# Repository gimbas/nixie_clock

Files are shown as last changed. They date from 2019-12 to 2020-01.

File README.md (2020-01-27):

# Nixie Clock

yet another nixie tube clock, esp32 wifi enabled, temperature and humidity sensing, air quality sensing.

## Built With

* esp-idf
* eagle cad

## Authors

* **Rafael Silva** - *initial work* - [gimbas](https://github.com/gimbas)

See also the list of [contributors](https://github.com/gimbas/nixie_clock/graphs/contributors) who participated in this project.

## License

<br />This work is licensed under a <a rel="license" href="http://creativecommons.org/licenses/by-sa/4.0/">Creative Commons Attribution-ShareAlike 4.0 International License</a>.

## Acknowledgments

* HV power supply development and testing - [tonyp7](https://github.com/tonyp7/)

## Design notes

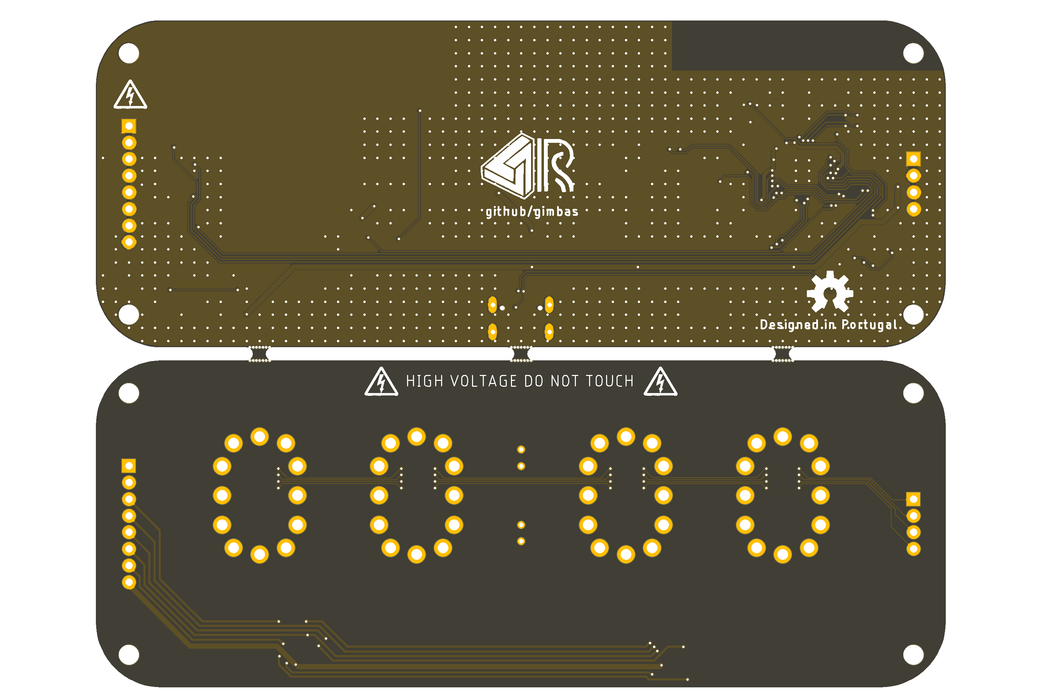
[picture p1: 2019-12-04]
pcb/nixie_clock_bot.png

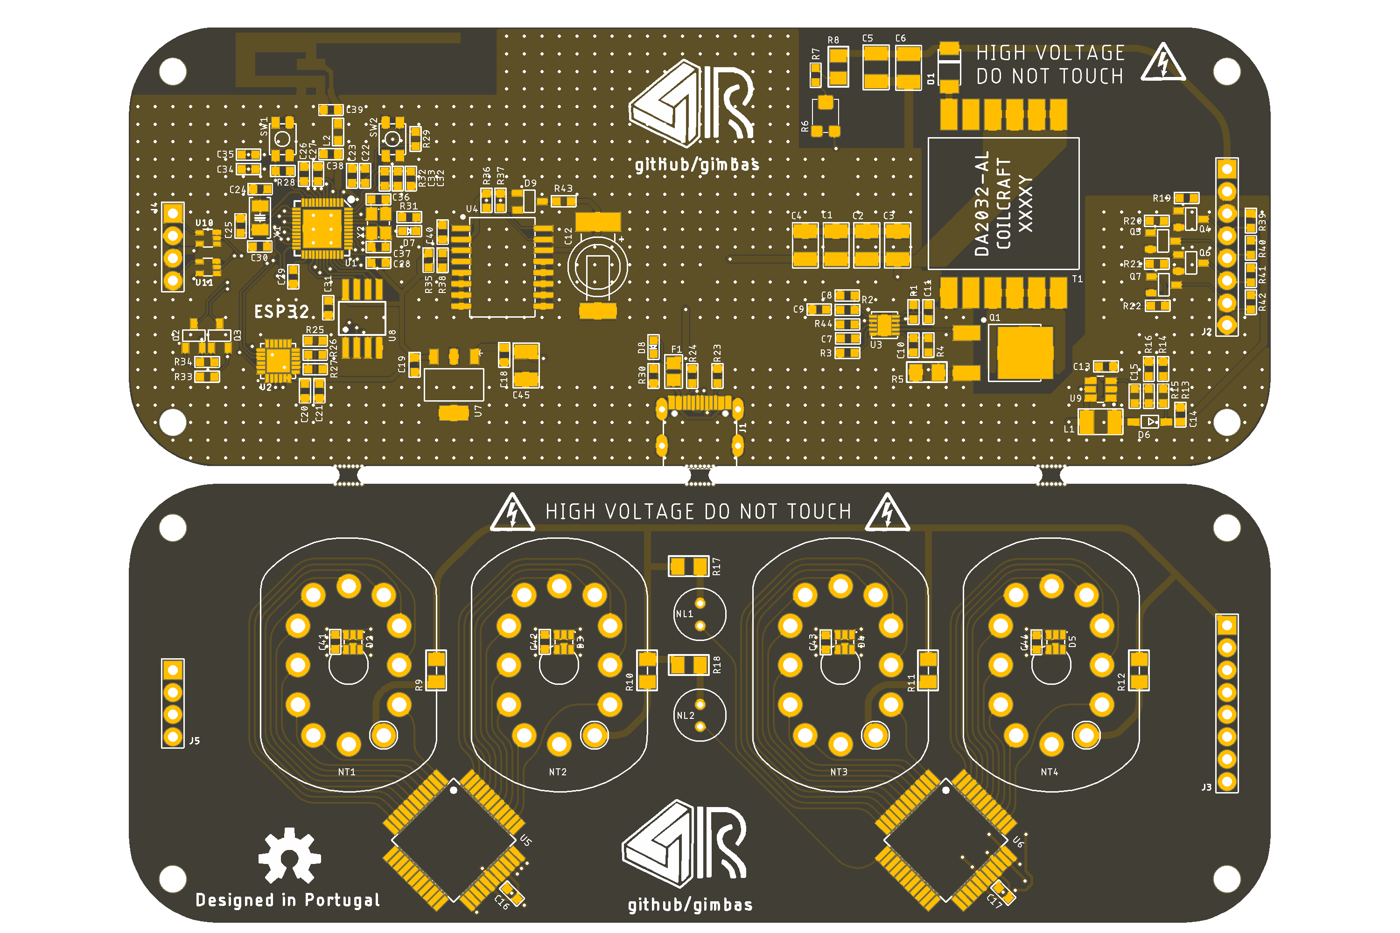
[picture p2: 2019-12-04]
pcb/nixie_clock_top.png

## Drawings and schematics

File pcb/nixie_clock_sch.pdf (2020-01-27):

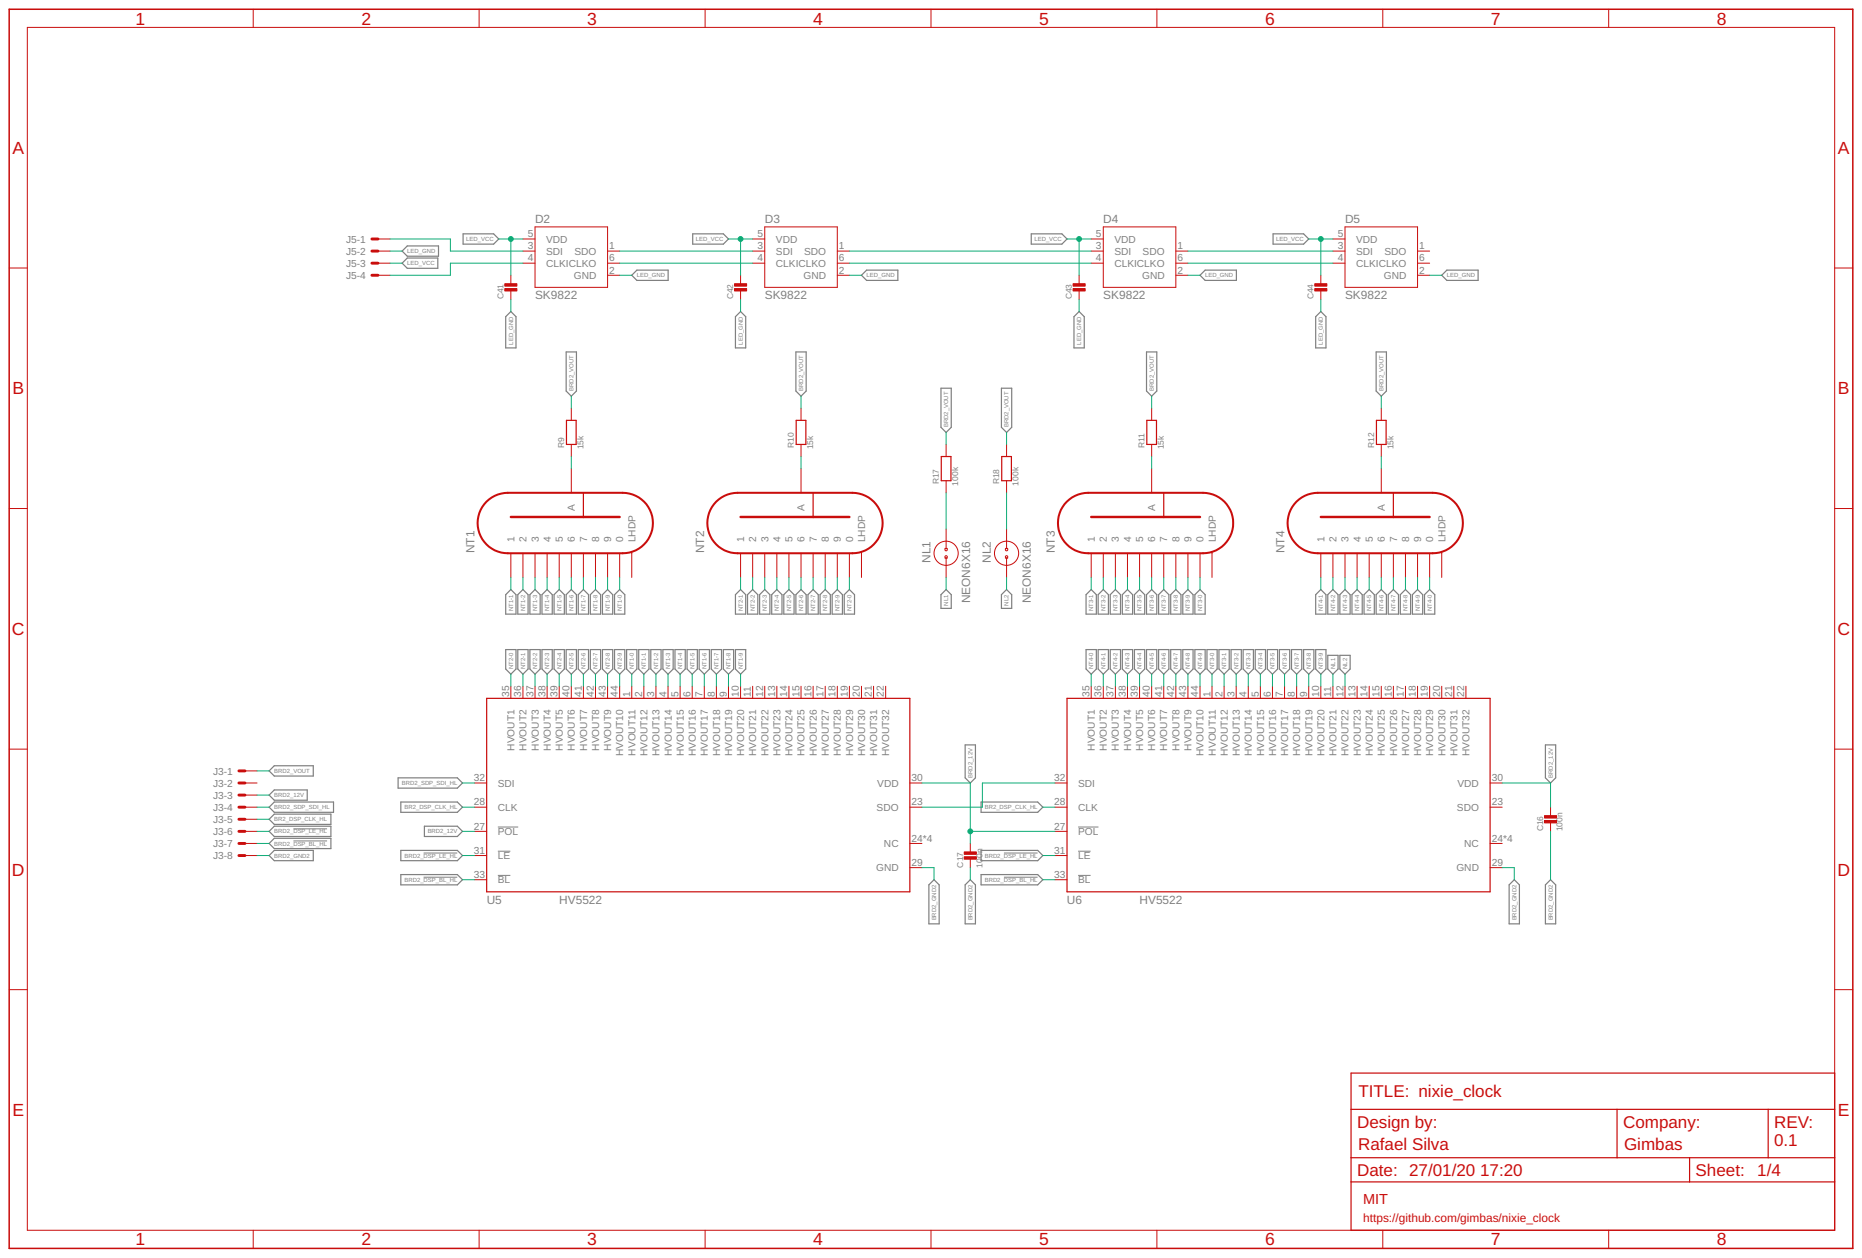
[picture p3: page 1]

Design by: Rafael Silva | Company: Gimbas | REV: 0.1

Date: 27/01/20 17:20 | Sheet: 1/4

MIT
https://github.com/gimbas/nixie_clock

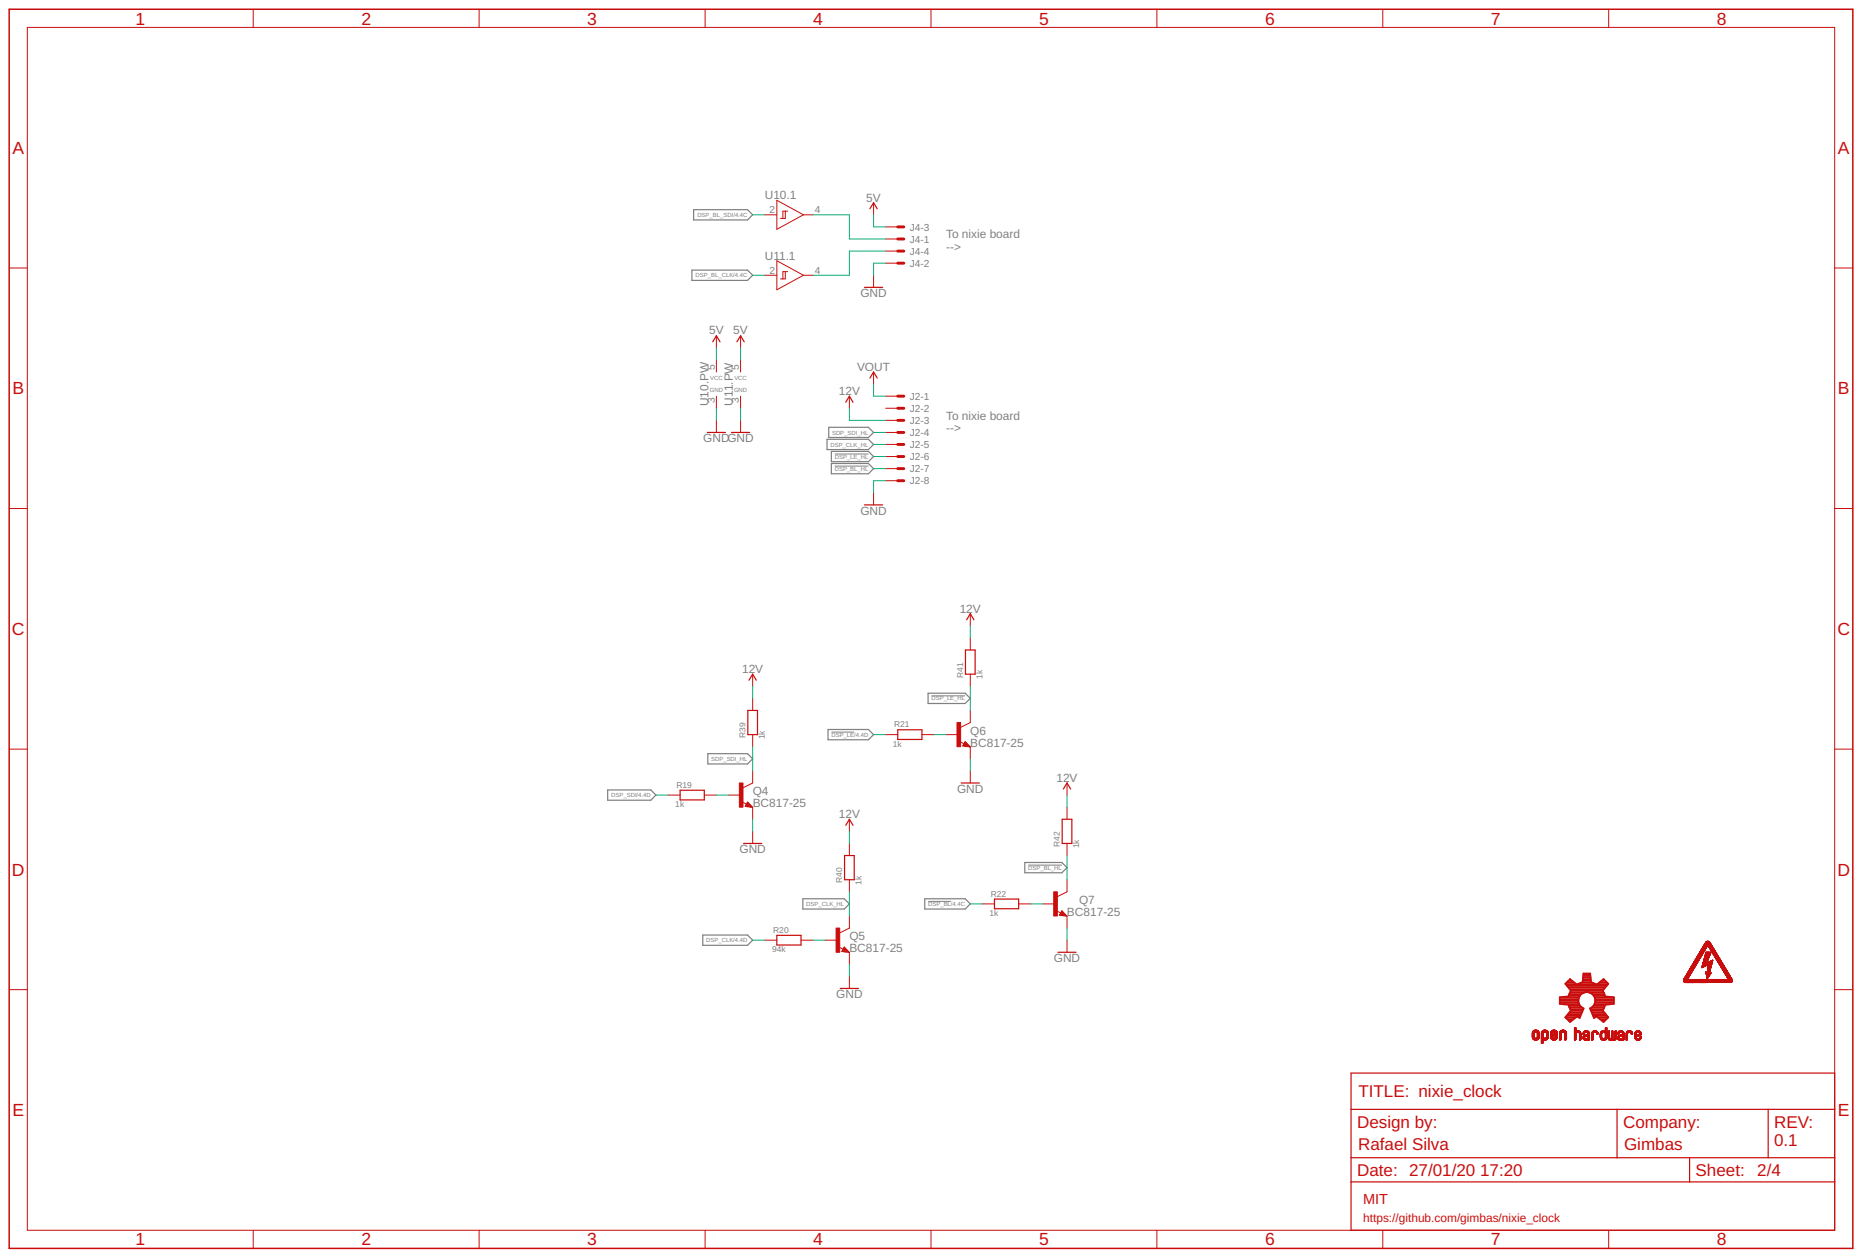
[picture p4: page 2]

Design by: Rafael Silva | Company: Gimbas | REV: 0.1

Date: 27/01/20 17:20 | Sheet: 2/4

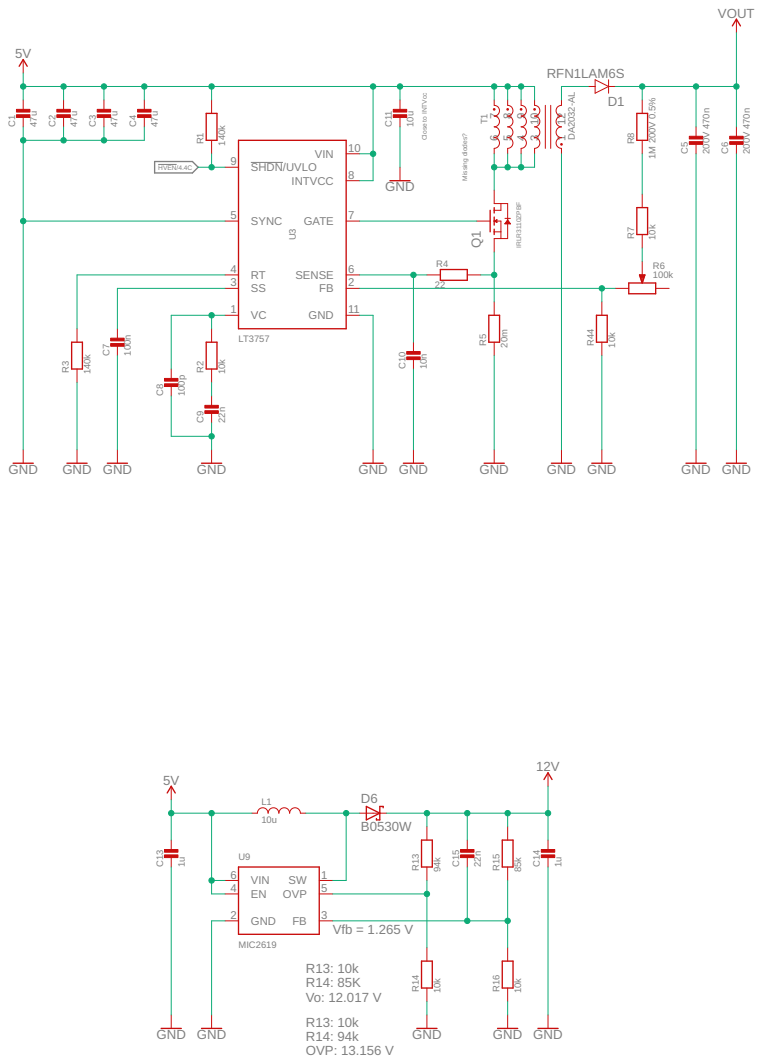
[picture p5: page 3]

Close to INTVcc Missing diodes?

Design by: Rafael Silva | Company: Gimbas | REV: 0.1

Date: 27/01/20 17:20 | Sheet: 3/4

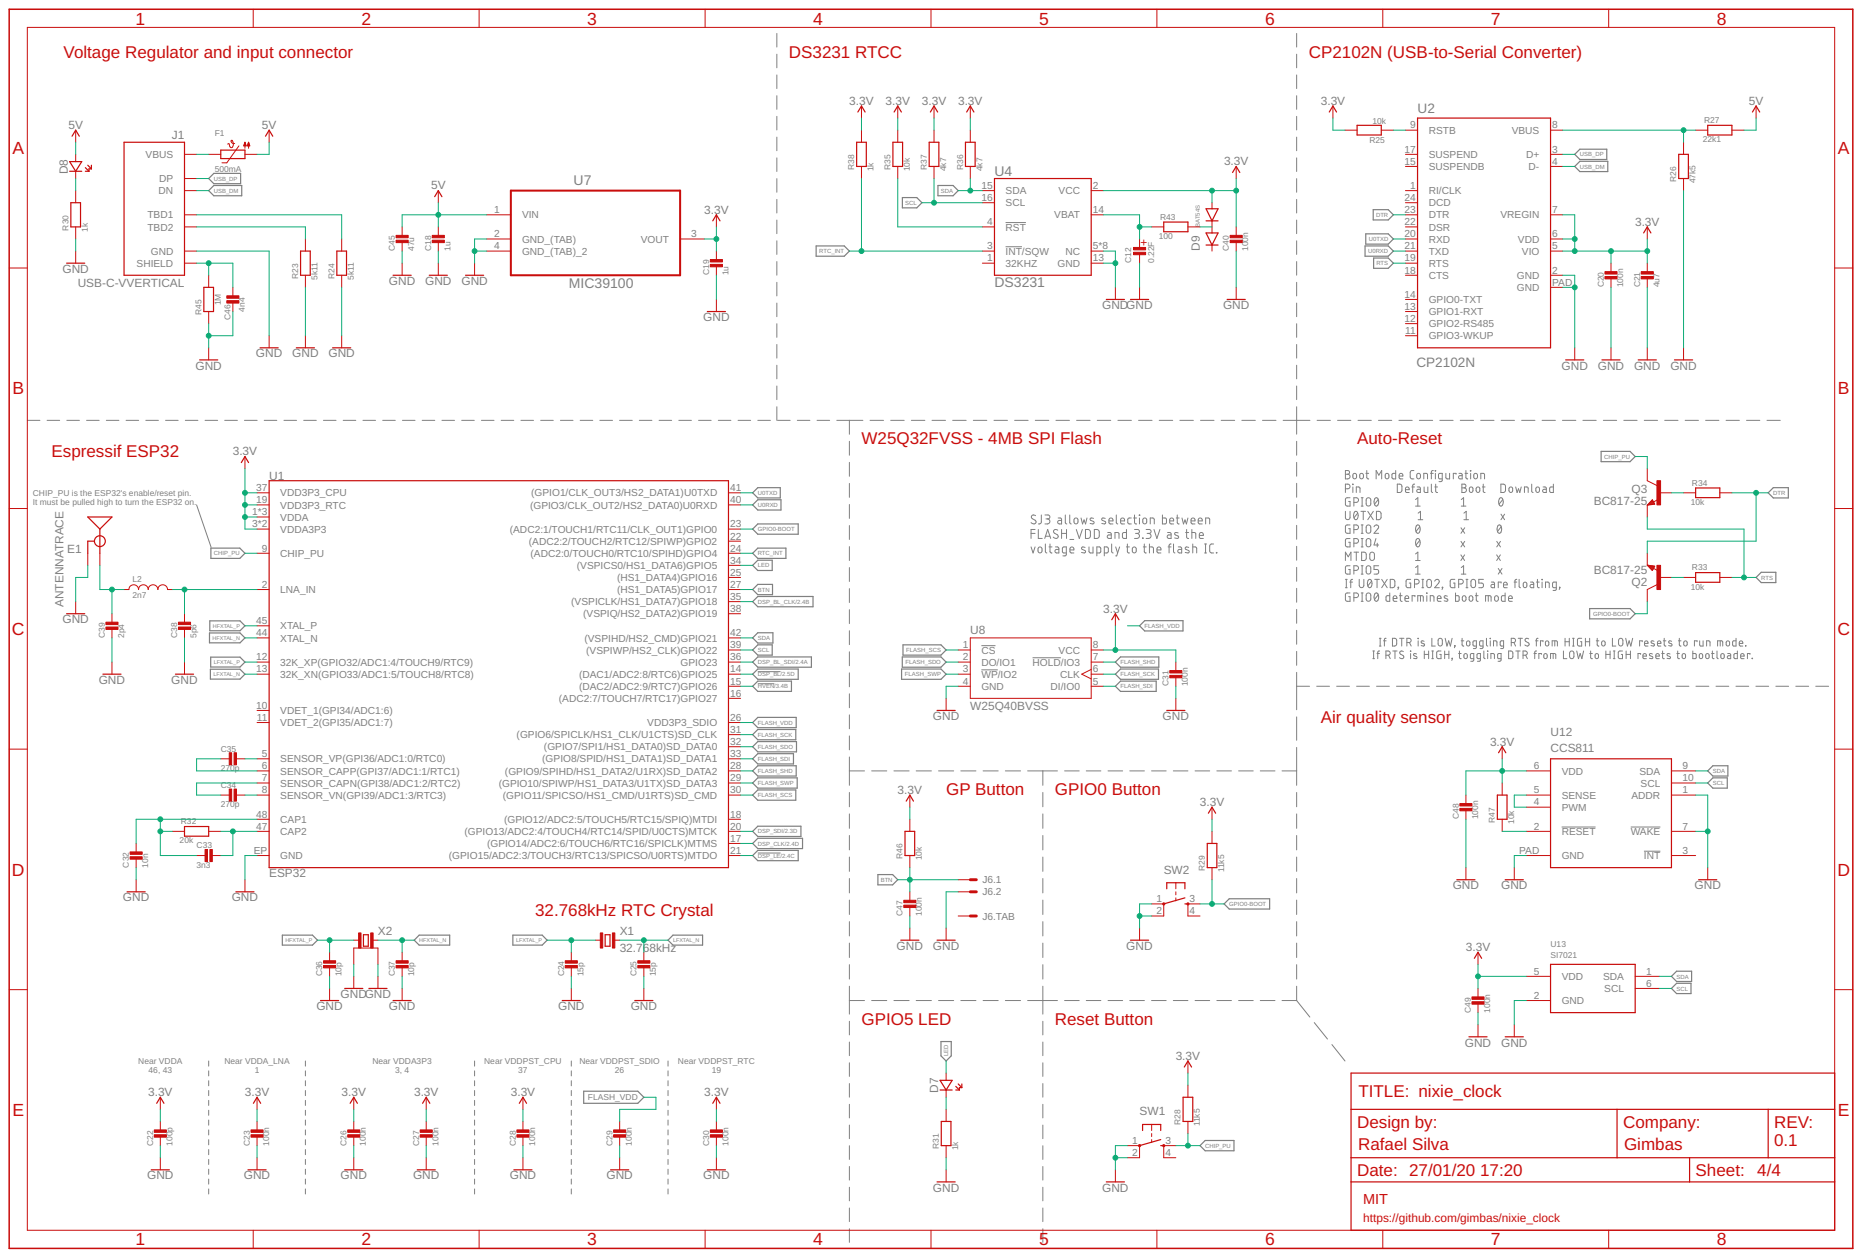
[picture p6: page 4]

CHIP_PU is the ESP32's enable/reset pin.
It must be pulled high to turn the ESP32 on.

Design by: Rafael Silva | Company: Gimbas | REV: 0.1

Date: 27/01/20 17:20 | Sheet: 4/4

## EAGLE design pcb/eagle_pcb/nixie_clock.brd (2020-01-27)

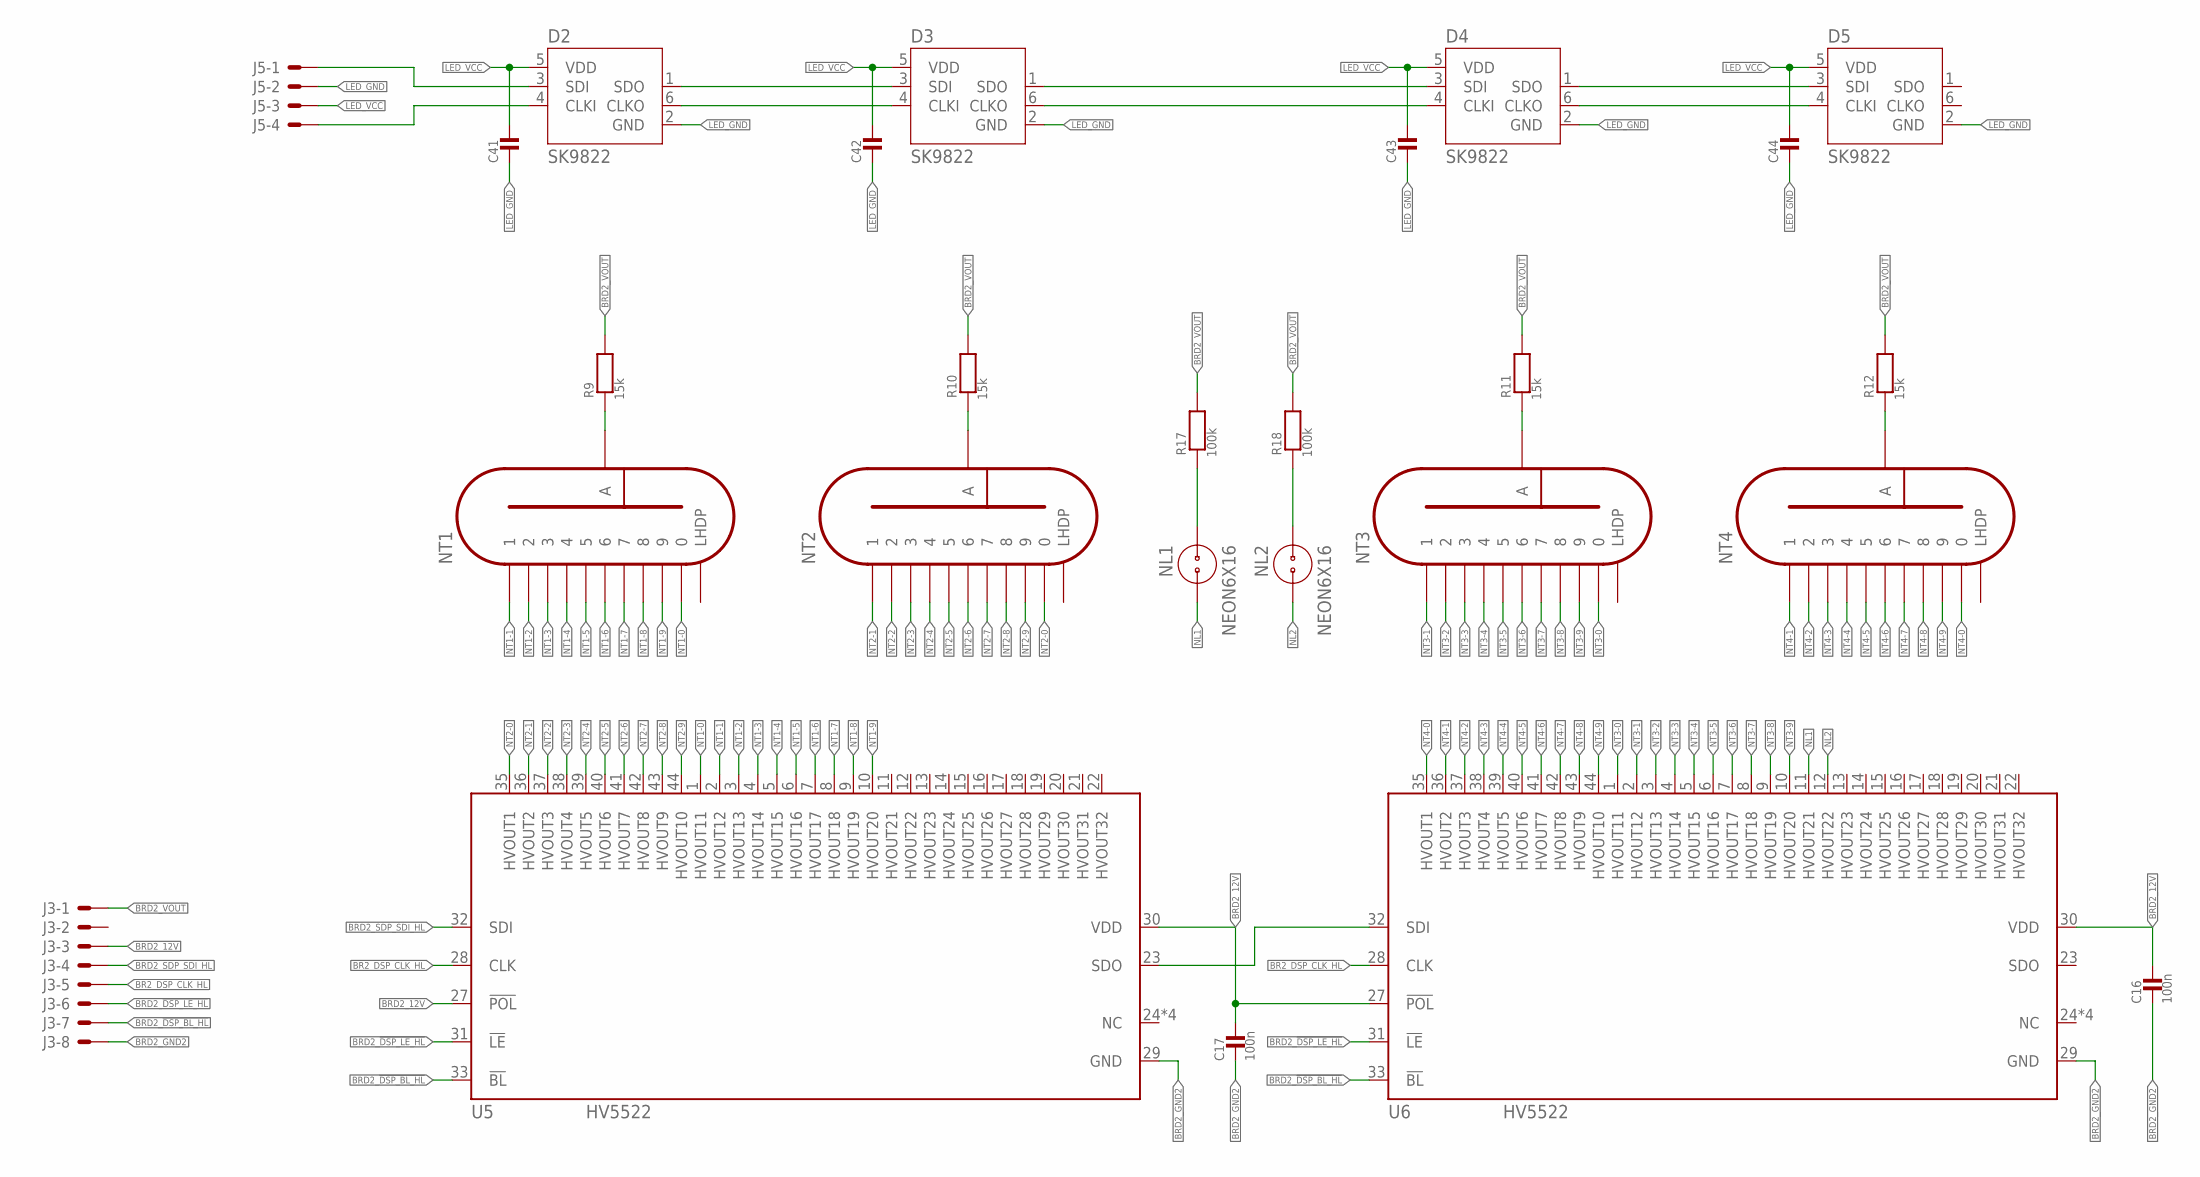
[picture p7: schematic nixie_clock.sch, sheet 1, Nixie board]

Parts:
C16, C17: 100n; 0603_WAVE
C41, C42, C43, C44: MLCC0603; 0603_WAVE
D2, D3, D4, D5: SK9822; 2020
J3: 8; 1X8_2.54
J5: 4; 1X4_2.54
NL1, NL2: NEON6X16; NL-6X16
NT1, NT2, NT3, NT4: IN-12B; IN-12
R9, R10, R11, R12: 15k; _1206
R17, R18: 100k; _1206
U5, U6: HV5522; QFP64

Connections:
BR2_DSP_CLK_HL: J3.5, U5.28 (CLK), U6.28 (CLK)
BRD2_12V: C16.P$1, C17.P$1, J3.3, U5.27 (!POL), U5.30 (VDD), U6.27 (!POL), U6.30 (VDD)
BRD2_!DSP_BL_HL: J3.7, U5.33 (!BL), U6.33 (!BL)
BRD2_!DSP_LE_HL: J3.6, U5.31 (!LE), U6.31 (!LE)
BRD2_GND2: C16.P$2, C17.P$2, J3.8, U5.29 (GND), U6.29 (GND)
BRD2_SDP_SDI_HL: J3.4, U5.32 (SDI)
BRD2_VOUT: J3.1, R9.2, R10.2, R11.2, R12.2, R17.2, R18.2
LED_GND: C41.P$2, C42.P$2, C43.P$2, C44.P$2, D2.2 (GND), D3.2 (GND), D4.2 (GND), D5.2 (GND), J5.2
LED_VCC: C41.P$1, C42.P$1, C43.P$1, C44.P$1, D2.5 (VDD), D3.5 (VDD), D4.5 (VDD), D5.5 (VDD), J5.3
unnamed: NT1.A, R9.1
unnamed: NT2.A, R10.1
unnamed: NT3.A, R11.1
unnamed: NT4.A, R12.1
unnamed: NL1.1, R17.1
unnamed: NL2.1, R18.1
unnamed: U5.23 (SDO), U6.32 (SDI)
unnamed: D2.3 (SDI), J5.1
unnamed: D2.4 (CLKI), J5.4
unnamed: D3.1 (SDO), D4.3 (SDI)
unnamed: D3.6 (CLKO), D4.4 (CLKI)
unnamed: D4.6 (CLKO), D5.4 (CLKI)
unnamed: D4.1 (SDO), D5.3 (SDI)
unnamed: D2.6 (CLKO), D3.4 (CLKI)
unnamed: D2.1 (SDO), D3.3 (SDI)
NL1: NL1.2, U6.11 (HVOUT21)
NL2: NL2.2, U6.12 (HVOUT22)
NT1-0: NT1.0, U5.1 (HVOUT11)
NT1-1: NT1.1, U5.2 (HVOUT12)
NT1-2: NT1.2, U5.3 (HVOUT13)
NT1-3: NT1.3, U5.4 (HVOUT14)
NT1-4: NT1.4, U5.5 (HVOUT15)
NT1-5: NT1.5, U5.6 (HVOUT16)
NT1-6: NT1.6, U5.7 (HVOUT17)
NT1-7: NT1.7, U5.8 (HVOUT18)
NT1-8: NT1.8, U5.9 (HVOUT19)
NT1-9: NT1.9, U5.10 (HVOUT20)
NT2-0: NT2.0, U5.35 (HVOUT1)
NT2-1: NT2.1, U5.36 (HVOUT2)
NT2-2: NT2.2, U5.37 (HVOUT3)
NT2-3: NT2.3, U5.38 (HVOUT4)
NT2-4: NT2.4, U5.39 (HVOUT5)
NT2-5: NT2.5, U5.40 (HVOUT6)
NT2-6: NT2.6, U5.41 (HVOUT7)
NT2-7: NT2.7, U5.42 (HVOUT8)
NT2-8: NT2.8, U5.43 (HVOUT9)
NT2-9: NT2.9, U5.44 (HVOUT10)
NT3-0: NT3.0, U6.1 (HVOUT11)
NT3-1: NT3.1, U6.2 (HVOUT12)
NT3-2: NT3.2, U6.3 (HVOUT13)
NT3-3: NT3.3, U6.4 (HVOUT14)
NT3-4: NT3.4, U6.5 (HVOUT15)
NT3-5: NT3.5, U6.6 (HVOUT16)
NT3-6: NT3.6, U6.7 (HVOUT17)
NT3-7: NT3.7, U6.8 (HVOUT18)
NT3-8: NT3.8, U6.9 (HVOUT19)
NT3-9: NT3.9, U6.10 (HVOUT20)
NT4-0: NT4.0, U6.35 (HVOUT1)
NT4-1: NT4.1, U6.36 (HVOUT2)
NT4-2: NT4.2, U6.37 (HVOUT3)
NT4-3: NT4.3, U6.38 (HVOUT4)
NT4-4: NT4.4, U6.39 (HVOUT5)
NT4-5: NT4.5, U6.40 (HVOUT6)
NT4-6: NT4.6, U6.41 (HVOUT7)
NT4-7: NT4.7, U6.42 (HVOUT8)
NT4-8: NT4.8, U6.43 (HVOUT9)
NT4-9: NT4.9, U6.44 (HVOUT10)

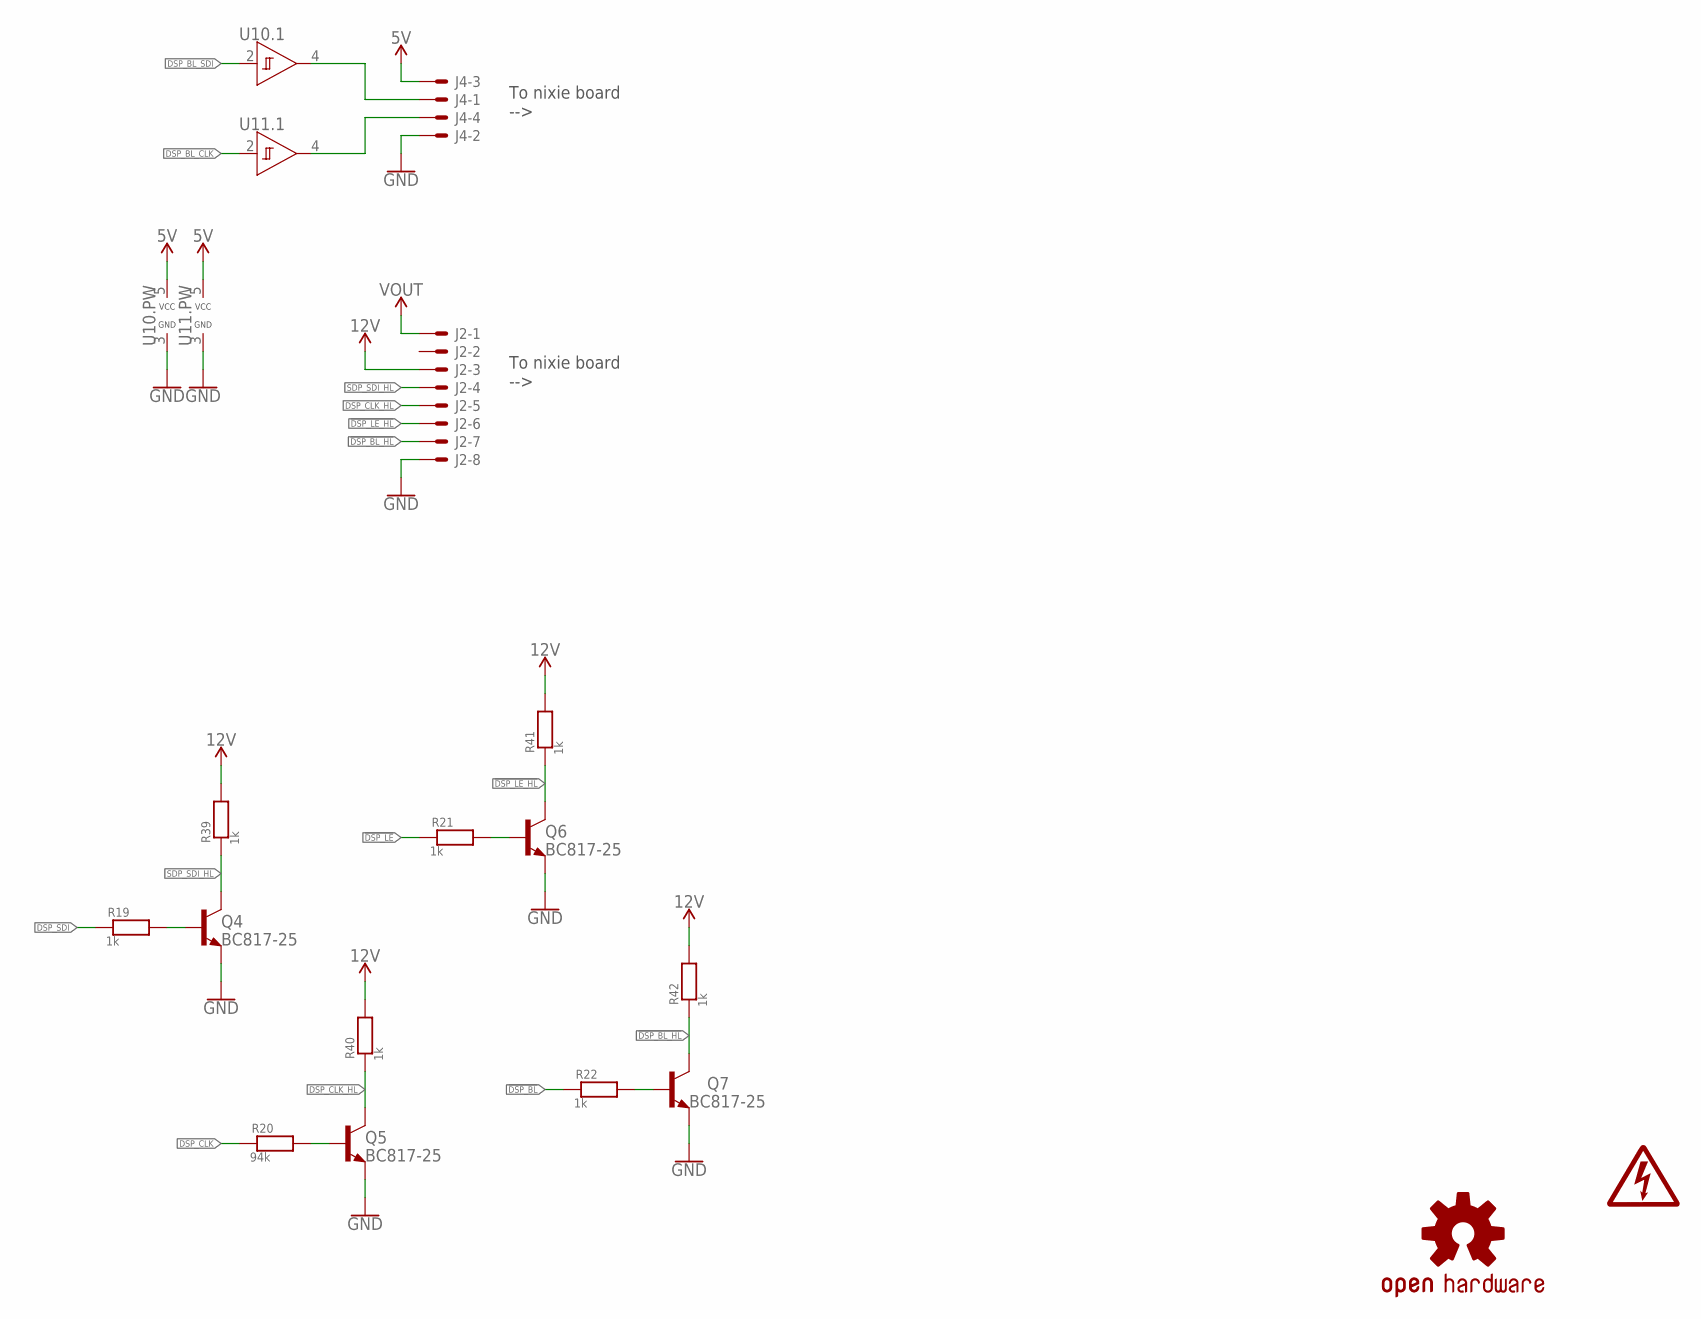
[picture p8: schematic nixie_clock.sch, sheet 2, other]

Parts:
J2: 8; 1X8_2.54
J4: 4; 1X4_2.54
LOGO3: OSHW-LOGOL; OSHW-LOGO-L
LOGO6: HV_WARNING
Q4, Q5, Q6, Q7: BC817-25; SOT-23-3
R19, R21, R22, R39, R40, R41, R42: 1k; 0603_WAVE
R20: 94k; 0603_WAVE
U10, U11: 74LVC1G17; SC70-5

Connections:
5V: J4.3, U10.5 (VCC), U11.5 (VCC); also elsewhere on the board
12V: J2.3, R39.P$2, R40.P$2, R41.P$2, R42.P$2; also elsewhere on the board
!DSP_BL: R22.P$1; also elsewhere on the board
!DSP_BL_HL: J2.7, Q7.P$3 (C03), R42.P$1
!DSP_LE: R21.P$1; also elsewhere on the board
!DSP_LE_HL: J2.6, Q6.P$3 (C03), R41.P$1
DSP_BL_CLK: U11.2 (A); also elsewhere on the board
DSP_BL_SDI: U10.2 (A); also elsewhere on the board
DSP_CLK: R20.P$1; also elsewhere on the board
DSP_CLK_HL: J2.5, Q5.P$3 (C03), R40.P$1
DSP_SDI: R19.P$1; also elsewhere on the board
GND: J2.8, J4.2, Q4.P$2 (EM2), Q5.P$2 (EM2), Q6.P$2 (EM2), Q7.P$2 (EM2), U10.3 (GND), U11.3 (GND); also elsewhere on the board
unnamed: Q4.P$1 (BA1), R19.P$2
unnamed: Q5.P$1 (BA1), R20.P$2
unnamed: Q7.P$1 (BA1), R22.P$2
unnamed: Q6.P$1 (BA1), R21.P$2
unnamed: J4.4, U11.4 (Y)
unnamed: J4.1, U10.4 (Y)
SDP_SDI_HL: J2.4, Q4.P$3 (C03), R39.P$1
VOUT: J2.1; also elsewhere on the board

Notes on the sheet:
To nixie board -->

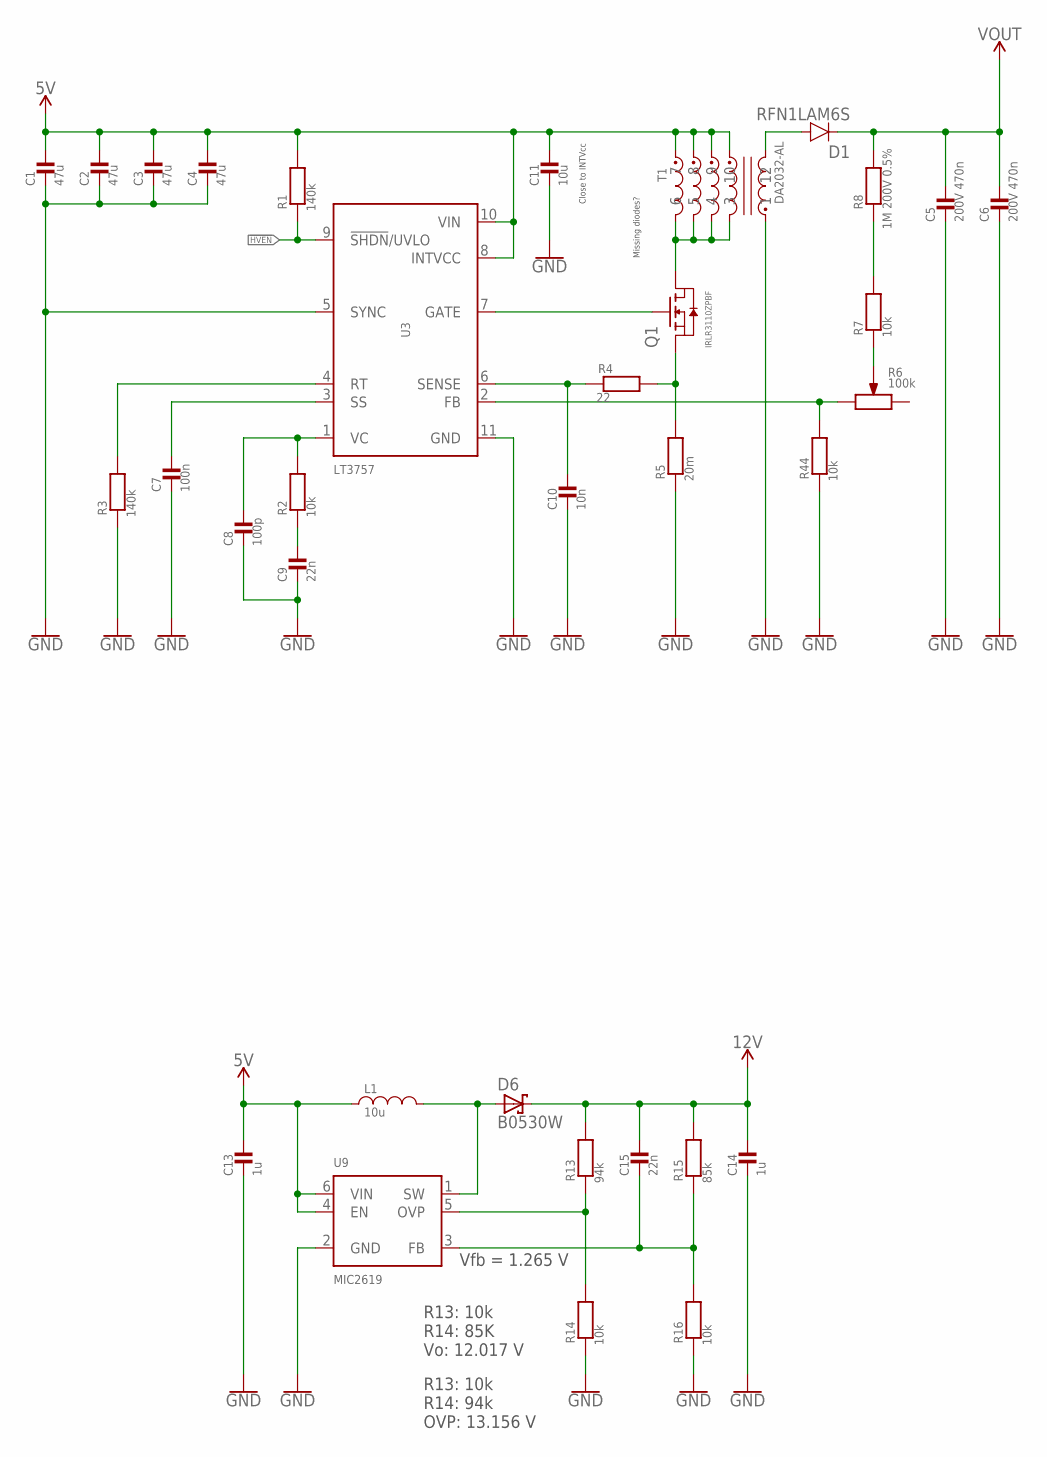
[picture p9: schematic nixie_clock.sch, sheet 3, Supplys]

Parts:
C1, C2, C3, C4: 47u; _1210
C5, C6: 200V 470n; _1210
C7: 100n; 0603_WAVE
C8: 100p; 0603_WAVE
C9, C15: 22n; 0603_WAVE
C10: 10n; 0603_WAVE
C11: 10u; 0603_WAVE
C13, C14: 1u; 0603_WAVE
D1: RFN1LAM6S; SOD-128
D6: B0530W; SOD-123
L1: 10u; _1210
Q1: IRLR3110ZPBF; D-PAK
R1, R3: 140k; 0603_WAVE
R2, R7, R14, R16, R44: 10k; 0603_WAVE
R4: 22; 0603_WAVE
R5: 20m; _1206
R6: 100k; TC33X
R8: 1M 200V 0.5%; _1206
R13: 94k; 0603_WAVE
R15: 85k; 0603_WAVE
T1: DA2032-AL
U3: LT3757; DFN10-2
U9: MIC2619; SOT-23-6N

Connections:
5V: C1.1, C2.1, C3.1, C4.1, C11.P$1, C13.P$1, L1.1, R1.P$2, T1.7, T1.8, T1.9, T1.10, U3.8 (INTVCC), U3.10 (VIN), U9.4 (EN), U9.6 (VIN); also elsewhere on the board
12V: C14.P$1, C15.P$1, D6.C, R13.P$2, R15.P$2; also elsewhere on the board
!HVEN: R1.P$1, U3.9 (!SHDN!/UVLO); also elsewhere on the board
GND: C1.2, C2.2, C3.2, C4.2, C5.2, C6.2, C7.P$2, C8.P$2, C9.P$2, C10.P$2, C11.P$2, C13.P$2, C14.P$2, R3.P$1, R5.1, R14.P$1, R16.P$1, R44.P$1, T1.1, U3.5 (SYNC), U3.11 (GND), U9.2 (GND); also elsewhere on the board
unnamed: D1.AN, T1.12
unnamed: C10.P$1, R4.P$1, U3.6 (SENSE)
unnamed: Q1.L (G1), U3.7 (GATE)
unnamed: Q1.P (D1), T1.3, T1.4, T1.5, T1.6
unnamed: Q1.R (S1), R4.P$2, R5.2
unnamed: R6.2, R7.P$1
unnamed: R7.P$2, R8.1
unnamed: C8.P$1, R2.P$2, U3.1 (VC)
unnamed: C9.P$1, R2.P$1
unnamed: C7.P$1, U3.3 (SS)
unnamed: R3.P$2, U3.4 (RT)
unnamed: D6.A, L1.2, U9.1 (SW)
unnamed: R13.P$1, R14.P$2, U9.5 (OVP)
unnamed: C15.P$2, R15.P$1, R16.P$2, U9.3 (FB)
unnamed: R6.3, R44.P$2, U3.2 (FB)
VOUT: C5.1, C6.1, D1.CAT, R8.2; also elsewhere on the board

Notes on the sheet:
Close to INTVcc
Missing diodes?
Vfb = 1.265 V
R13: 10k R14: 85K Vo: 12.017 V
R13: 10k R14: 94k OVP: 13.156 V

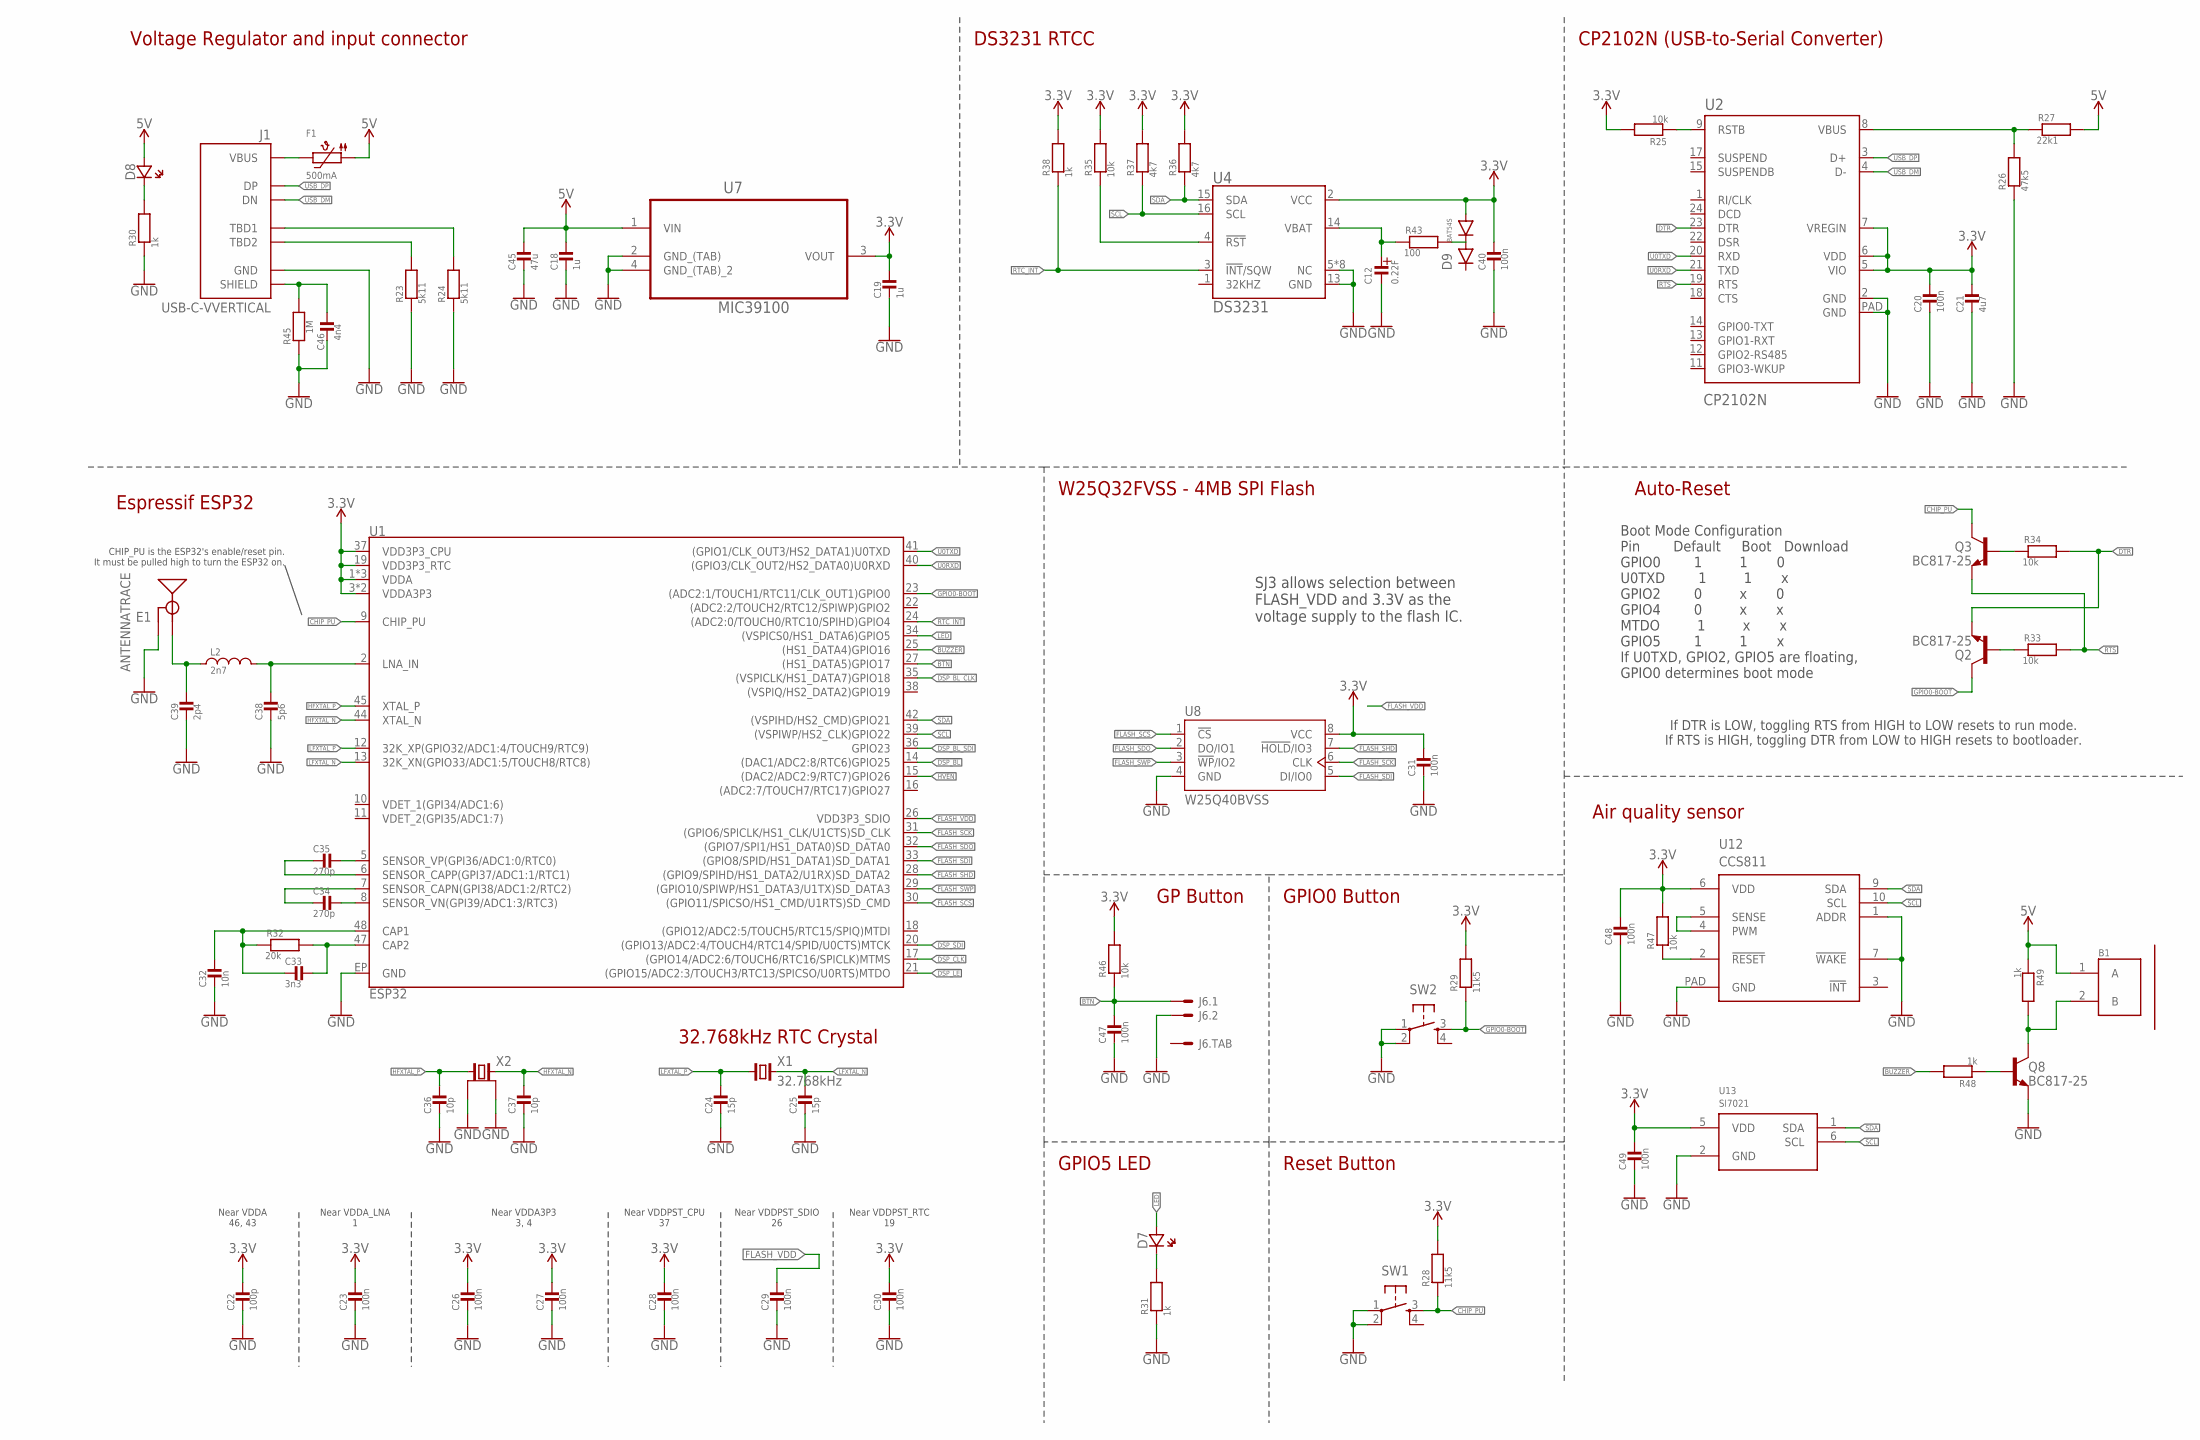
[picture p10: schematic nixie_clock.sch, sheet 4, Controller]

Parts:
B1: PKLCS1212E2400-R1; BUZZ_PIEZO_SMD
C12: 0.22F; DSK-614/621
C18, C19: 1u; 0603_WAVE
C20, C23, C26, C27, C28, C29, C30, C31, C40, C47, C48, C49: 100n; 0603_WAVE
C21: 4u7; 0603_WAVE
C22: 100p; 0603_WAVE
C24, C25: 15p; 0603_WAVE
C32: 10n; 0603_WAVE
C33: 3n3; 0603_WAVE
C34, C35: 270p; 0603_WAVE
C36, C37: 10p; 0603_WAVE
C38: 5p6; 0603_WAVE
C39: 2p4; 0603_WAVE
C45: 47u; _1210
C46: 4n4; 0603_WAVE
D7, D8: LED0603; CHIPLED_0603
D9: BAT54S; SOT-23-3
E1: ANTENNATRACE; TRACE_ANTENNA_2.4GHZ_25.7MM
F1: 500mA; 0805
J1: USB-C-VVERTICAL; USB-C-V
J6: PH-2; JST_PH_SMD_2
L2: 2n7; _0603
Q2, Q3, Q8: BC817-25; SOT-23-3
R23, R24: 5k11; 0603_WAVE
R25, R33, R34, R35, R46, R47: 10k; 0603_WAVE
R26: 47k5; 0603_WAVE
R27: 22k1; 0603_WAVE
R28, R29: 11k5; 0603_WAVE
R30, R31, R38, R48, R49: 1k; 0603_WAVE
R32: 20k; 0603_WAVE
R36, R37: 4k7; 0603_WAVE
R43: 100; 0603_WAVE
R45: 1M; 0603_WAVE
SW1, SW2: PUSH_BUTTON3X4X2; 3X4X2
U1: ESP32; QFN48-0.4MM
U2: CP2102N; QFN24
U4: DS3231; SOIC-16
U7: MIC39100; SOT230P700X180-4N
U8: W25Q40BVSS; SO08-SS
U12: CCS811; LGA10
U13: SI7021; DFN6
X1: 32.768kHz; 2-SMD-3215
X2: 26MHz; 4-SMD-3225

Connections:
3.3V: C19.P$1, C20.P$1, C21.P$1, C22.P$1, C23.P$1, C26.P$1, C27.P$1, C28.P$1, C30.P$1, C31.P$1, C40.P$1, C48.P$1, C49.P$1, D9.P$1 (1), R25.P$2, R28.P$2, R29.P$2, R35.P$2, R36.P$2, R37.P$2, R38.P$2, R46.P$2, R47.P$2, U1.1 (VDDA), U1.3 (VDDA3P3), U1.4 (VDDA3P3), U1.19 (VDD3P3_RTC), U1.37 (VDD3P3_CPU), U1.43 (VDDA), U1.46 (VDDA), U2.5 (VIO), U2.6 (VDD), U2.7 (VREGIN), U4.2 (VCC), U7.3 (VOUT), U8.8 (VCC), U12.6 (VDD), U13.5 (VDD)
5V: B1.1 (A), C18.P$1, C45.1, D8.A (AN), F1.1, R27.P$2, R49.P$1, U7.1 (VIN); also elsewhere on the board
!DSP_BL: U1.14 ((DAC1/ADC2:8/RTC6)GPIO25); also elsewhere on the board
!DSP_LE: U1.21 ((GPIO15/ADC2:3/TOUCH3/RTC13/SPICSO/U0RT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); also elsewhere on the board
!HVEN: U1.15 ((DAC2/ADC2:9/RTC7)GPIO26); also elsewhere on the board
BTN: C47.P$1, J6.1, R46.P$1, U1.27 ((HS1_DATA5)GPIO17)
BUZZER: R48.P$2, U1.25 ((HS1_DATA4)GPIO16)
CHIP_PU: Q3.P$3 (C03), R28.P$1, SW1.3 (4), U1.9 (CHIP_PU)
DSP_BL_CLK: U1.35 ((VSPICLK/HS1_DATA7)GPIO18); also elsewhere on the board
DSP_BL_SDI: U1.36 (GPIO23); also elsewhere on the board
DSP_CLK: U1.17 ((GPIO14/ADC2:6/TOUCH6/RTC16/SPICLK)MTMS); also elsewhere on the board
DSP_SDI: U1.20 ((GPIO13/ADC2:4/TOUCH4/RTC14/SPID/U0CTS)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); also elsewhere on the board
DTR: Q2.P$2 (EM2), R34.P$2, U2.23 (DTR)
FLASH_SCK: U1.31 ((GPIO6/SPICLK/HS1_CLK/U1CTS)SD_CLK), U8.6 (CLK)
FLASH_SCS: U1.30 ((GPIO11/SPICSO/HS1_CMD/U1RTS)SD_CMD), U8.1 (!CS!)
FLASH_SDI: U1.33 ((GPIO8/SPID/HS1_DATA1)SD_DATA1), U8.5 (DI/IO0)
FLASH_SDO: U1.32 ((GPIO7/SPI1/HS1_DATA0)SD_DATA0), U8.2 (DO/IO1)
FLASH_SHD: U1.28 ((GPIO9/SPIHD/HS1_DATA2/U1RX)SD_DATA2), U8.7 (!HOLD!/IO3)
FLASH_SWP: U1.29 ((GPIO10/SPIWP/HS1_DATA3/U1TX)SD_DATA3), U8.3 (!WP!/IO2)
FLASH_VDD: C29.P$1, U1.26 (VDD3P3_SDIO)
GND: C12.2 (CA), C18.P$2, C19.P$2, C20.P$2, C21.P$2, C22.P$2, C23.P$2, C24.P$2, C25.P$2, C26.P$2, C27.P$2, C28.P$2, C29.P$2, C30.P$2, C31.P$2, C32.P$2, C36.P$2, C37.P$2, C38.P$2, C39.P$2, C40.P$2, C45.2, C46.P$2, C47.P$2, C48.P$2, C49.P$2, E1.GND, E1.GND2 (GND), J1.1 (GND), J1.2 (GND), J1.15 (GND), J1.16 (GND), J6.2, Q8.P$2 (EM2), R23.P$1, R24.P$1, R26.P$1, R30.P$1, R31.P$1, R45.P$1, SW1.1, SW1.2, SW2.1, SW2.2, U1.EP (GND), U2.2 (GND), U2.PAD (GND), U4.5 (NC), U4.6 (NC), U4.7 (NC), U4.8 (NC), U4.9 (NC), U4.10 (NC), U4.11 (NC), U4.12 (NC), U4.13 (GND), U7.2 (GND_(TAB)), U7.4 (GND_(TAB)_2), U8.4 (GND), U12.1 (ADDR), U12.7 (!WAKE), U12.PAD (GND), U13.2 (GND), X2.1 (GND), X2.3 (GND); also elsewhere on the board
GPIO0-BOOT: Q2.P$3 (C03), R29.P$1, SW2.3 (4), U1.23 ((ADC2:1/TOUCH1/RTC11/CLK_OUT1)GPIO0)
HFXTAL_N: C37.P$1, U1.44 (XTAL_N), X2.4 (2)
HFXTAL_P: C36.P$1, U1.45 (XTAL_P), X2.2 (1)
LED: D7.A (AN), U1.34 ((VSPICS0/HS1_DATA6)GPIO5)
LFXTAL_N: C25.P$1, U1.13 (32K_XN(GPIO33/ADC1:5/TOUCH8/RTC8)), X1.2
LFXTAL_P: C24.P$1, U1.12 (32K_XP(GPIO32/ADC1:4/TOUCH9/RTC9)), X1.1
unnamed: C39.P$1, E1.ANT (SIGNAL), L2.1
unnamed: D9.P$3 (3), R43.P$2
unnamed: C46.P$1, J1.S1 (SHIELD), J1.S2 (SHIELD), J1.S3 (SHIELD), J1.S4 (SHIELD), R45.P$2
unnamed: R47.P$1, U12.2 (!RESET)
unnamed: U12.4 (PWM), U12.5 (SENSE)
unnamed: B1.2 (B), Q8.P$3 (C03), R49.P$2
unnamed: Q8.P$1 (BA1), R48.P$1
unnamed: F1.2, J1.3 (VBUS), J1.4 (VBUS), J1.13 (VBUS), J1.14 (VBUS)
unnamed: J1.6 (TBD2), R23.P$2
unnamed: J1.11 (TBD1), R24.P$2
unnamed: R25.P$1, U2.9 (RSTB)
unnamed: D8.C (CA), R30.P$2
unnamed: R26.P$2, R27.P$1, U2.8 (VBUS)
unnamed: D7.C (CA), R31.P$2
unnamed: C33.P$1, R32.P$2, U1.47 (CAP2)
unnamed: C34.P$1, U1.8 (SENSOR_VN(GPI39/ADC1:3/RTC3))
unnamed: C32.P$1, C33.P$2, R32.P$1, U1.48 (CAP1)
unnamed: C35.P$1, U1.5 (SENSOR_VP(GPI36/ADC1:0/RTC0))
unnamed: C34.P$2, U1.7 (SENSOR_CAPN(GPI38/ADC1:2/RTC2))
unnamed: C35.P$2, U1.6 (SENSOR_CAPP(GPI37/ADC1:1/RTC1))
unnamed: C38.P$1, L2.2, U1.2 (LNA_IN)
unnamed: Q2.P$1 (BA1), R33.P$1
unnamed: Q3.P$1 (BA1), R34.P$1
unnamed: C12.1 (AN), R43.P$1, U4.14 (VBAT)
unnamed: R35.P$1, U4.4 (!RST)
RTC_INT: R38.P$1, U1.24 ((ADC2:0/TOUCH0/RTC10/SPIHD)GPIO4), U4.3 (!INT!/SQW)
RTS: Q3.P$2 (EM2), R33.P$2, U2.19 (RTS)
SCL: R37.P$1, U1.39 ((VSPIWP/HS2_CLK)GPIO22), U4.16 (SCL), U12.10 (SCL), U13.6 (SCL)
SDA: R36.P$1, U1.42 ((VSPIHD/HS2_CMD)GPIO21), U4.15 (SDA), U12.9 (SDA), U13.1 (SDA)
U0RXD: U1.40 ((GPIO3/CLK_OUT2/HS2_DATA0)U0RXD), U2.21 (TXD)
U0TXD: U1.41 ((GPIO1/CLK_OUT3/HS2_DATA1)U0TXD), U2.20 (RXD)
USB_DM: J1.7 (DN), J1.10 (DN), U2.4 (D-)
USB_DP: J1.8 (DP), J1.9 (DP), U2.3 (D+)

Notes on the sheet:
Near VDDA 46, 43
Near VDDA_LNA 1
Near VDDA3P3 3, 4
Near VDDPST_CPU 37
Near VDDPST_SDIO 26
Near VDDPST_RTC 19
Boot Mode Configuration Pin Default Boot Download GPIO0 1 1 0 U0TXD 1 1 x GPIO2 0 x 0 GPIO4 0 x x MTDO 1 x x GPIO5 1 1 x If U0TXD, GPIO2, GPIO5 are floating, GPIO0 determines boot mode
CP2102N (USB-to-Serial Converter)
Voltage Regulator and input connector
Auto-Reset
Espressif ESP32
W25Q32FVSS - 4MB SPI Flash
32.768kHz RTC Crystal
GPIO0 Button
Reset Button
GPIO5 LED
SJ3 allows selection between FLASH_VDD and 3.3V as the voltage supply to the flash IC.
If DTR is LOW, toggling RTS from HIGH to LOW resets to run mode. If RTS is HIGH, toggling DTR from LOW to HIGH resets to bootloader.
CHIP_PU is the ESP32's enable/reset pin. It must be pulled high to turn the ESP32 on.
DS3231 RTCC
GP Button
Air quality sensor

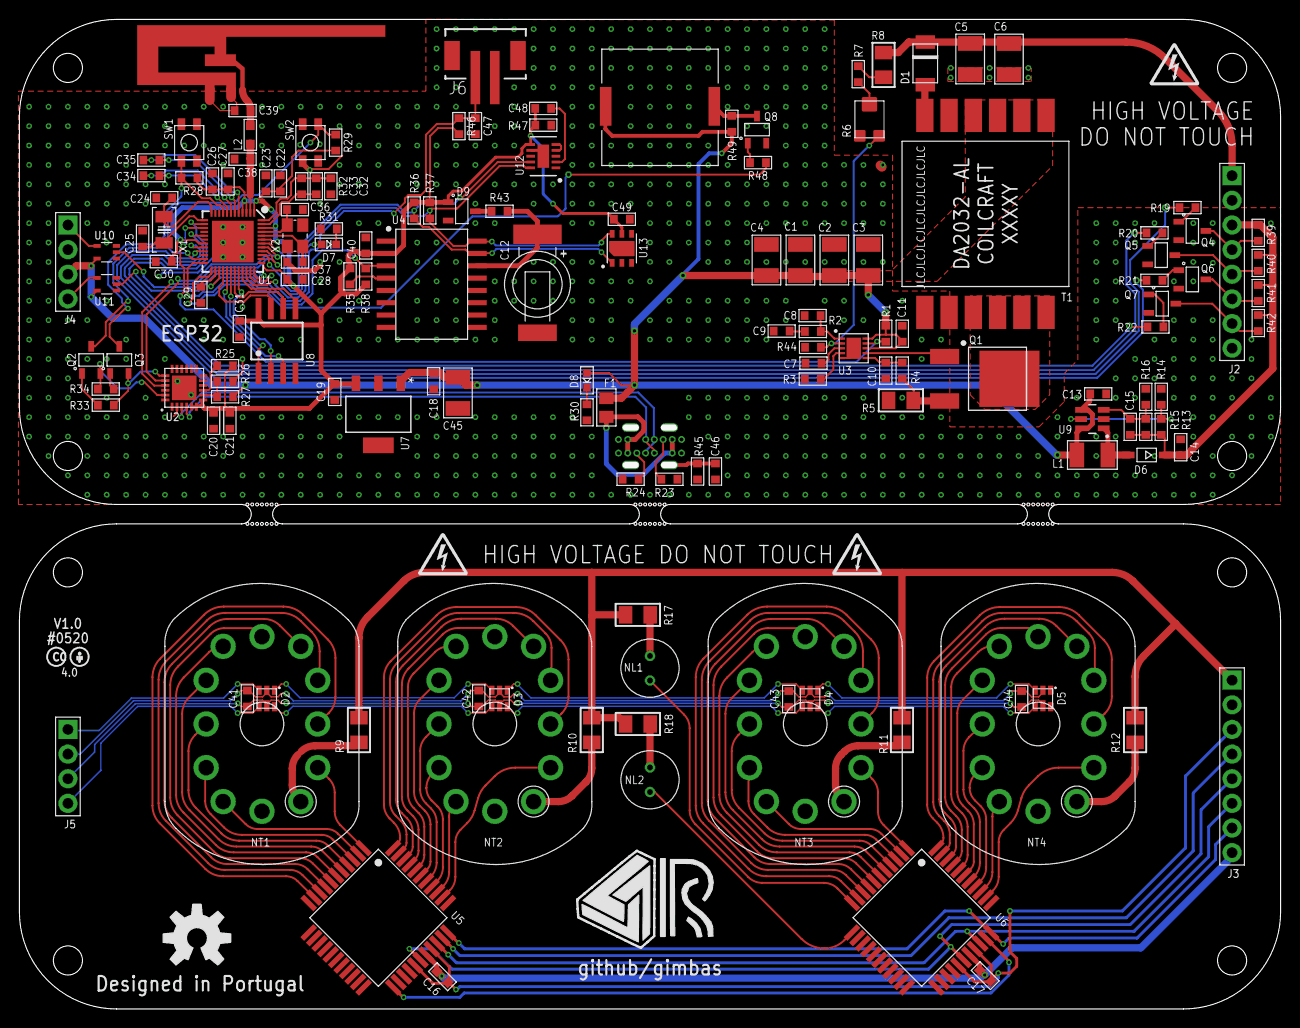
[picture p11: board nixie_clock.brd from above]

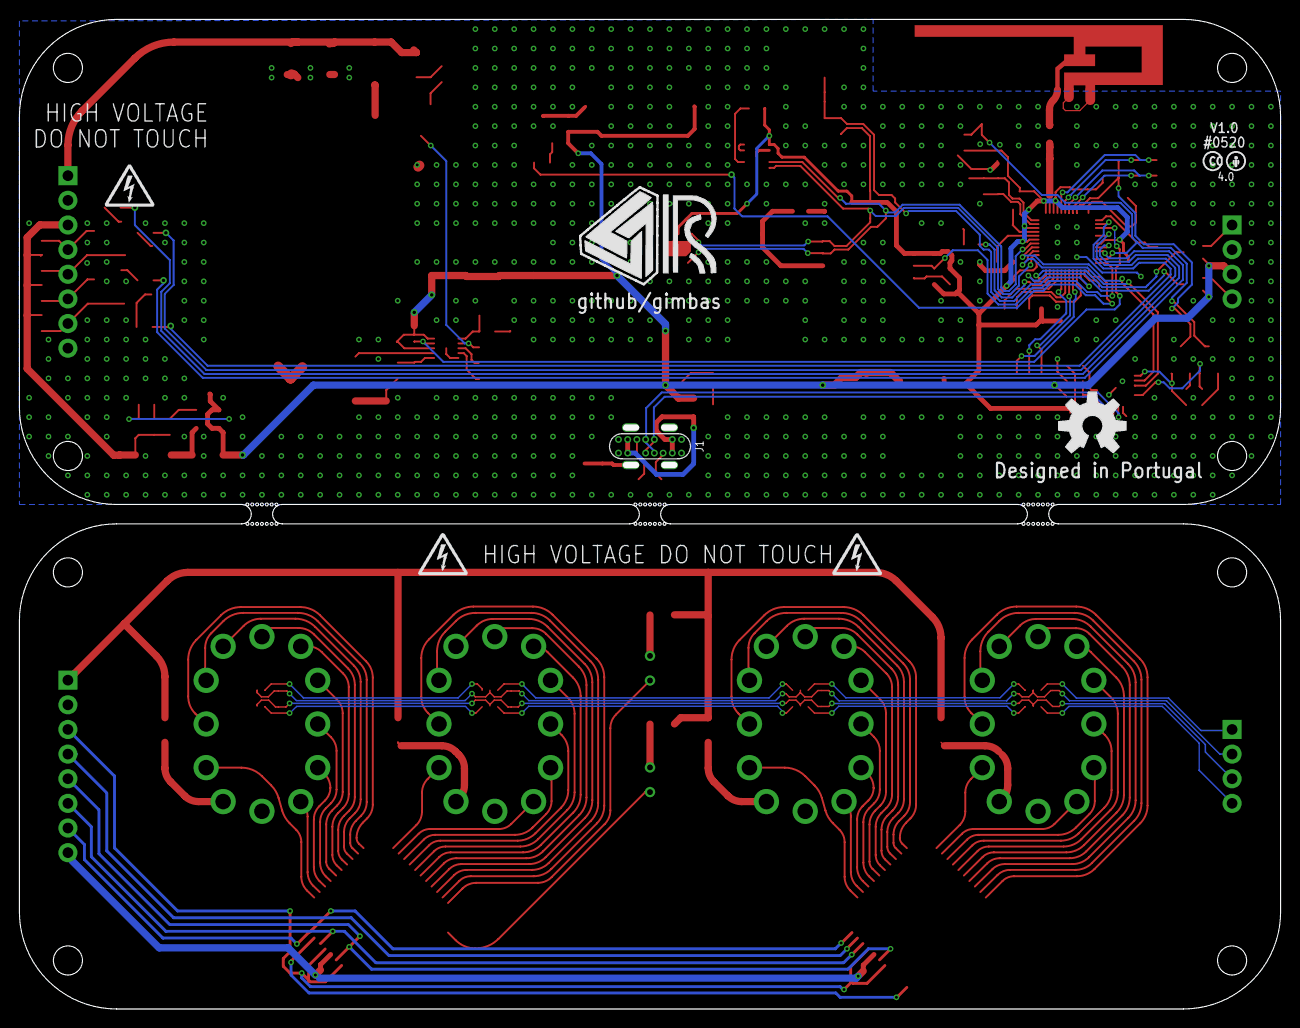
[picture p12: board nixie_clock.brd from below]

Board: 2 copper layers, 130.0 x 102.0 mm, 160 parts (6 on the bottom side), 153 nets.

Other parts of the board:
LOGO1, LOGO4, LOGO5, LOGO7, LOGO13: HV_WARNING
LOGO2: OSHW-LOGOL; OSHW-LOGO-L
U$1, U$3: RAFAEL_SILVA_10MM_ALT

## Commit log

2019-11-29 sch and pcb outline
    [nixie_clock.brd, nixie_clock.sch]
2019-12-04 rough pcb done
    [nixie_clock.brd, nixie_clock.sch]
2019-12-04 finished board -TODO change usb connector
    [nixie_clock.brd, nixie_clock.sch]
2019-12-05 changed usb connector
    [nixie_clock.brd, nixie_clock.sch]
2020-01-18 corrected usb pd resistor values
    [nixie_clock.brd, nixie_clock.sch]
2020-01-23 small fixes
    [nixie_clock.brd]
2020-01-27 ready for production
    [nixie_clock.brd, nixie_clock.sch]
2020-01-27 LICENSE update
    [nixie_clock.brd, nixie_clock.sch]
2020-01-27 added buzzer
    [nixie_clock.brd, nixie_clock.sch]

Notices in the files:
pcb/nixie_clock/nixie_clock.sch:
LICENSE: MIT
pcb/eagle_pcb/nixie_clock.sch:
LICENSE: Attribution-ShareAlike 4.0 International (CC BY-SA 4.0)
